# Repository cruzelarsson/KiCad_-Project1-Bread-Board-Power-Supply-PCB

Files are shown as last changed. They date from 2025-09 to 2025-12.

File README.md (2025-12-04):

This project — Simple BreadBoard Power Supply — was supported by PCBWay through their PCB prototyping sponsorship program.

PCBWay provided high-quality manufactured boards that arrived perfectly aligned and finished. The fabrication quality was excellent, with sharp silkscreen printing, clean solder masks, and precise drill accuracy.

A huge thanks to PCBWay for their support in helping bring this project to life. Their fast turnaround and reliable service made the prototyping process straightforward and efficient.

Below you will find the printed out board; the missing components will be added and uploaded soon. Thank you!





-------------------------------------------------------------------------------------------------------------------------------------------------------

3D Layout (Final Diagram)





-----------------------------------------------------------------------------------------------------------------------------------

PCB Layout with board characteristics




-----------------------------------------------------------------------------------------------------------------------------------
Schematic Layout 



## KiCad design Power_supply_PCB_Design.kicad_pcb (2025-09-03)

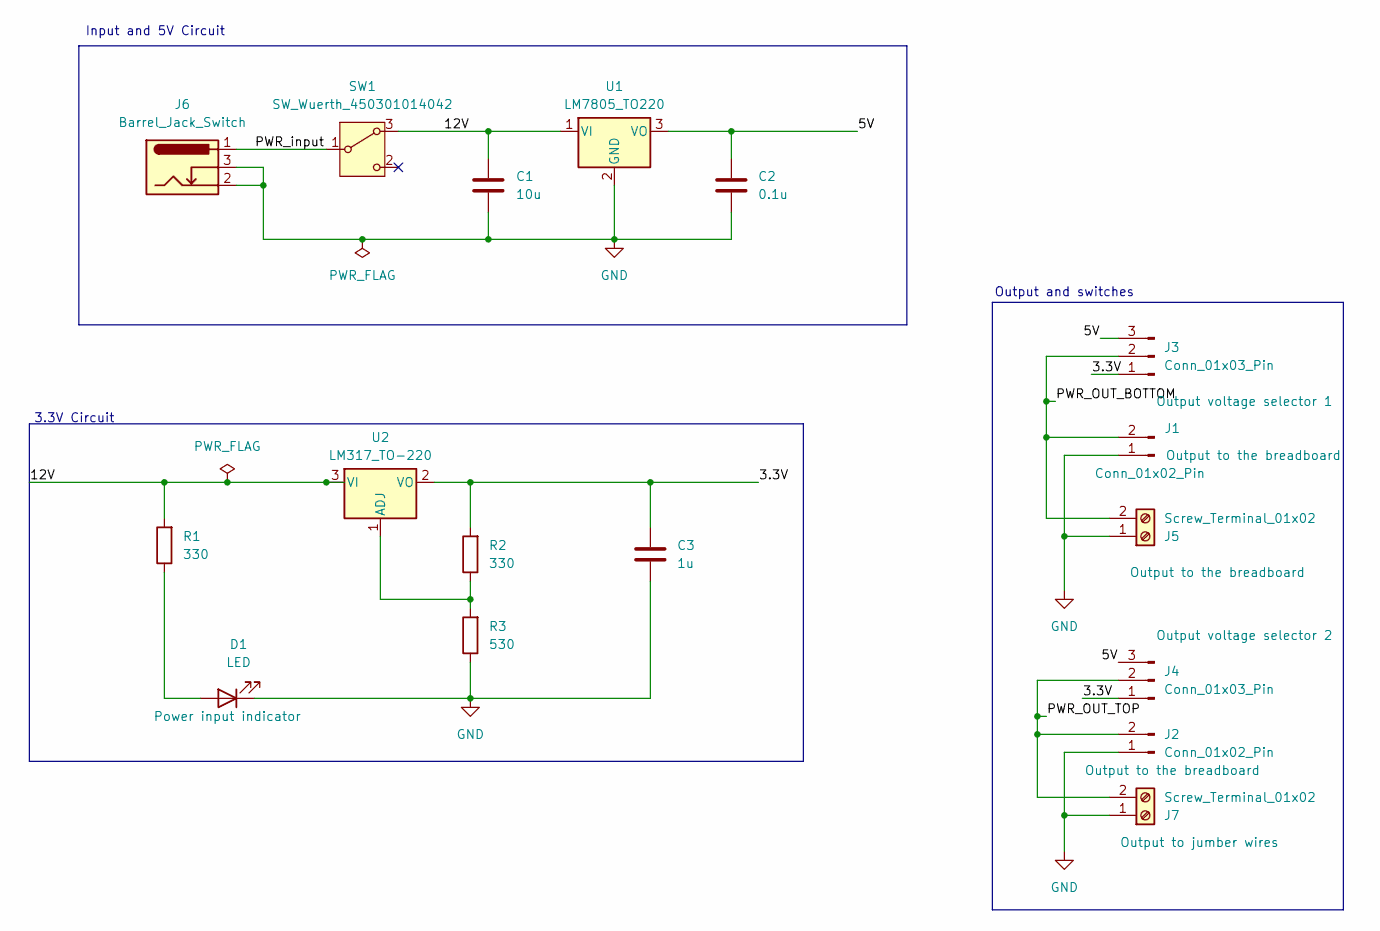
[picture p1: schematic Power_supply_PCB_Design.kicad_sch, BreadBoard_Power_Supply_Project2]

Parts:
C1: 10u; C_Disc_D3.0mm_W1.6mm_P2.50mm
C2: 0.1u; C_Disc_D3.0mm_W1.6mm_P2.50mm
C3: 1u; C_Disc_D3.0mm_W1.6mm_P2.50mm
D1: LED; LED_D5.0mm
J1, J2: Conn_01x02_Pin; PinHeader_1x02_P2.54mm_Vertical
J3, J4: Conn_01x03_Pin; PinHeader_1x03_P2.54mm_Vertical
J5, J7: Screw_Terminal_01x02; TerminalBlock_bornier-2_P5.08mm
J6: Barrel_Jack_Switch; BarrelJack_Horizontal
R1, R2: 330; R_Axial_DIN0204_L3.6mm_D1.6mm_P7.62mm_Horizontal
R3: 530; R_Axial_DIN0204_L3.6mm_D1.6mm_P7.62mm_Horizontal
SW1: SW_Wuerth_450301014042; SW_Slide-03_Wuerth-WS-SLTV_10x2.5x6.4_P2.54mm
U1: LM7805_TO220; TO-220-3_Vertical
U2: LM317_TO-220; TO-220-3_Vertical

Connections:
/3.3V: C3.1, J3.1, J4.1, R2.2, U2.2 (VO)
/5V: C2.1, J3.3, J4.3, U1.3 (VO)
/12V: C1.1, R1.2, SW1.3 (A), U1.1 (VI), U2.3 (VI)
/PWR_OUT_BOTTOM: J1.2, J3.2, J5.2
/PWR_OUT_TOP: J2.2, J4.2, J7.2
/PWR_input: J6.1, SW1.1 (B)
GND: C1.2, C2.2, C3.2, D1.1 (K), J1.1, J2.1, J5.1, J6.2, J6.3, J7.1, R3.1, U1.2 (GND)
unnamed: D1.2 (A), R1.1
unnamed: R2.1, R3.2, U2.1 (ADJ)

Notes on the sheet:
3.3V Circuit
Input and 5V Circuit
Output and switches

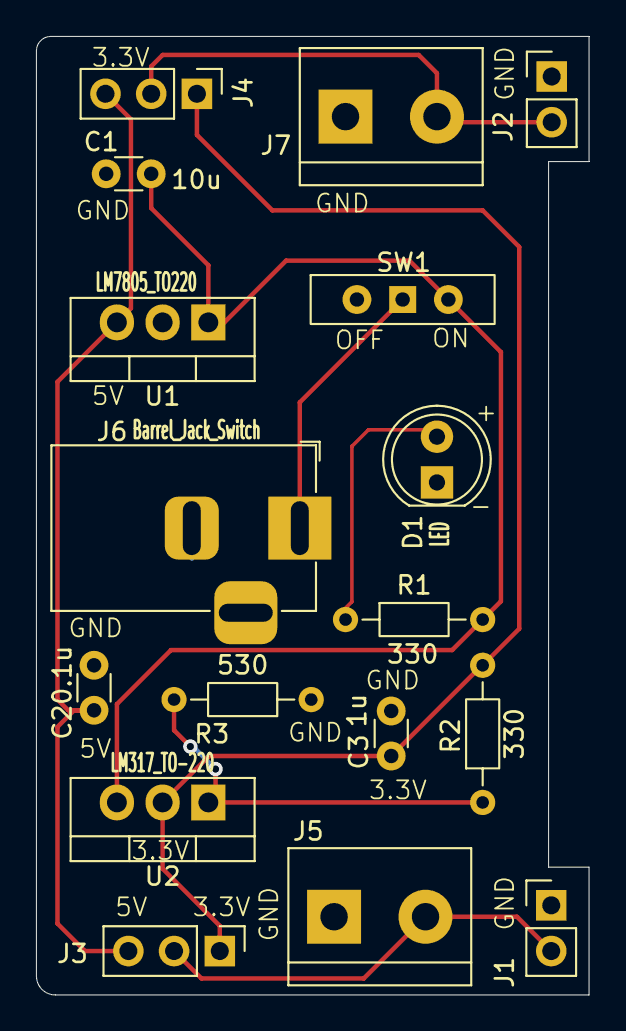
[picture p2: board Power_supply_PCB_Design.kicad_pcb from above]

Board: 2 copper layers, 30.7 x 53.2 mm, 17 parts (0 on the bottom side), 9 nets.

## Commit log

2025-09-01 Complete project of a simple Breadboard powersupply.
    [Power_supply_PCB_Design.kicad_pcb]
2025-09-03 Additional Bug Fixes
    [Power_supply_PCB_Design.kicad_pcb, Power_supply_PCB_Design.kicad_sch]
